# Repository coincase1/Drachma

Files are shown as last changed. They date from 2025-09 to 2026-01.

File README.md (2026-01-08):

30% Left-Handed Hall Effect Keypad

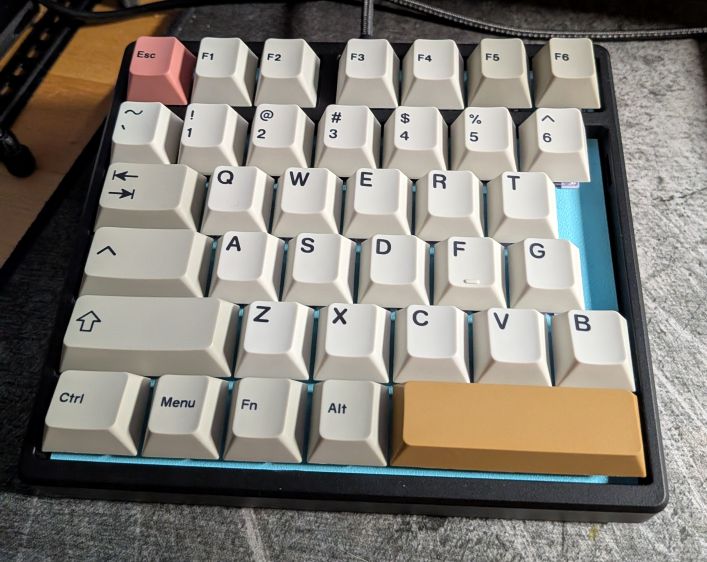
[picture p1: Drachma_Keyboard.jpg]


Based on / Inspired by [Peppapigh's HE60](https://github.com/peppapighs/HE60).

This keyboard is a PCB swap of the [Kisnt 34 Key Numpad](https://www.amazon.com/gp/product/B0C1H8V52D?smid=A1QSA46GV4FLI2&psc=1). With modifications to the top of the case using a hobby saw, this PCB fits inside of that case. The Drachma PCB connects to the Kisnt USB daughterboard using the provided Flat Conductor Cable. It also features a connection for a Pico-EZmate connector featured on Unified Daughterboards.

For anyone looking at this design at a later date, please be mindful of the Analog-to-Digital pins on the STM32F446 microcontroller. These can be verified on Sheets 46-56 of the STM32F446T MC Manual.

For HE switches, my recommendation are either OH49E-S or SS39ET from Honeywell. The OH49E-S are clones of these switches and these are featured in a number of big box HE board builds.

All Kicad and Firmware represents the latest (V3) Drachma build.

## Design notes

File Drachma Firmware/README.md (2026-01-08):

# Drachma

Drachma is a 37 key left-handed "30%" Hall-effect keyboard. The firmware here is for HMK.

- **Keyboard Maintainer**: [coincase]
- **Hardware Support**: [peppapighs/HE60](https://github.com/peppapighs/HE60)
- **Bootloader**: Factory STM32 DFU bootloader. Enter the bootloader through the following methods:
  - Hold **BOOT** button while plugging in the keyboard.
  - Press the `SP_BOOT` binding.
  - Use the web configurator.

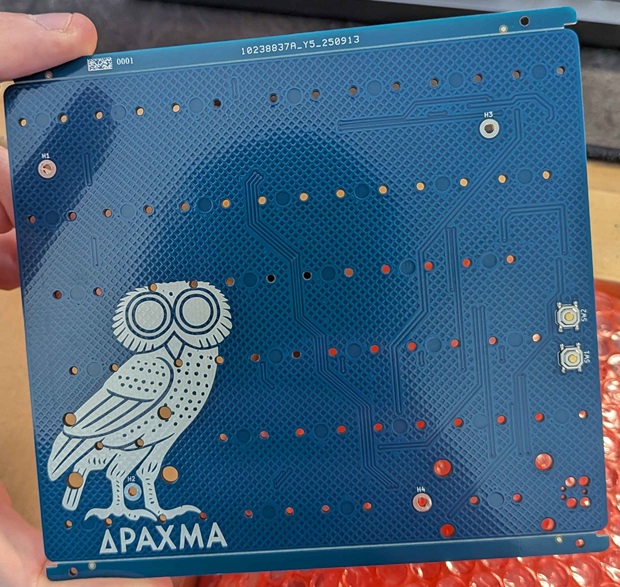
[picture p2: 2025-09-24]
Drachma V1_Front.jpg

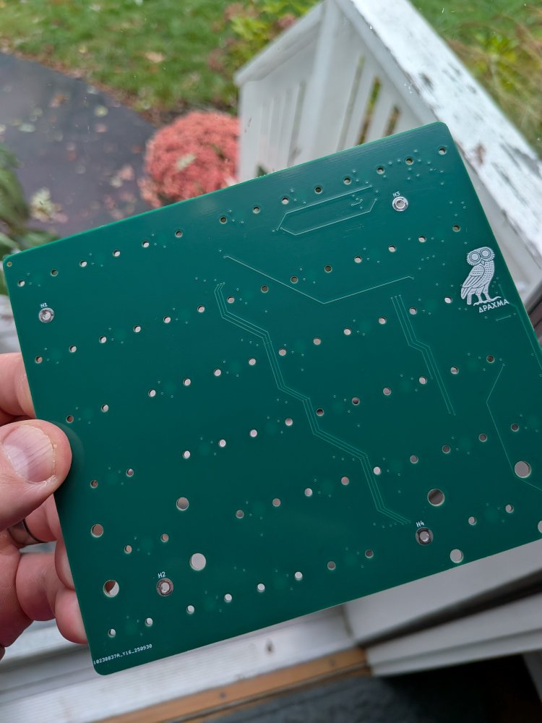
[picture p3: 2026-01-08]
Drachma V2_Front.jpg

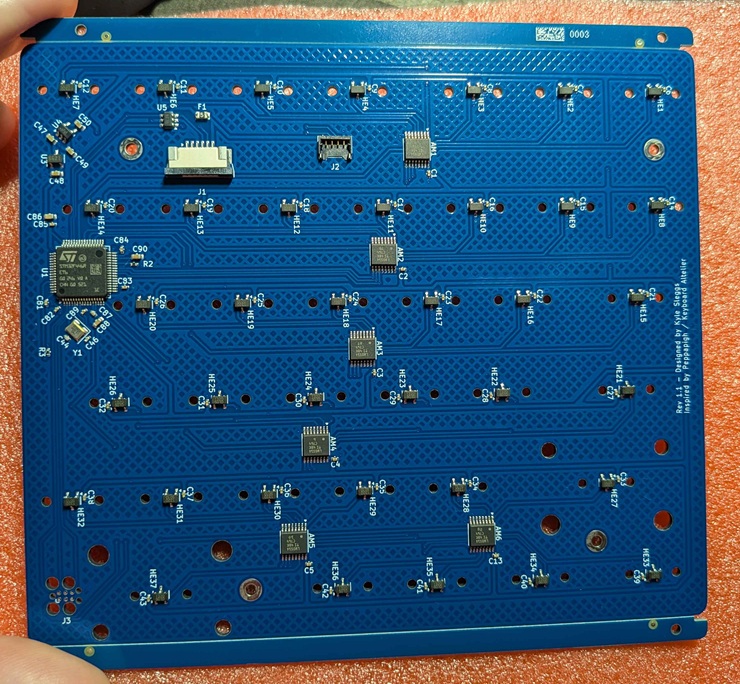
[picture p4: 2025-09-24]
Drachma V1_Back.jpg

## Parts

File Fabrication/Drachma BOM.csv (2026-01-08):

Comment | Designator | Value | Footprint | JLCPCB Part #
Analog Multiplexer | AM1 | SN74LV4051A | TSSOP-16_4.4x5mm_P0.65mm | C7793
Analog Multiplexer | AM2 | SN74LV4051A | TSSOP-16_4.4x5mm_P0.65mm | C7793
Analog Multiplexer | AM3 | SN74LV4051A | TSSOP-16_4.4x5mm_P0.65mm | C7793
Analog Multiplexer | AM4 | SN74LV4051A | TSSOP-16_4.4x5mm_P0.65mm | C7793
Analog Multiplexer | AM5 | SN74LV4051A | TSSOP-16_4.4x5mm_P0.65mm | C7793
Analog Multiplexer | AM6 | SN74LV4051A | TSSOP-16_4.4x5mm_P0.65mm | C7793
100n | C1 | 100n | C_0402_1005Metric | C1525
100n | C2 | 100n | C_0402_1005Metric | C1525
100n | C3 | 100n | C_0402_1005Metric | C1525
100n | C4 | 100n | C_0402_1005Metric | C1525
100n | C5 | 100n | C_0402_1005Metric | C1525
100n | C6 | 100n | C_0402_1005Metric | C1525
100n | C7 | 100n | C_0402_1005Metric | C1525
100n | C8 | 100n | C_0402_1005Metric | C1525
100n | C9 | 100n | C_0402_1005Metric | C1525
100n | C10 | 100n | C_0402_1005Metric | C1525
100n | C11 | 100n | C_0402_1005Metric | C1525
100n | C12 | 100n | C_0402_1005Metric | C1525
100n | C13 | 100n | C_0402_1005Metric | C1525
100n | C14 | 100n | C_0402_1005Metric | C1525
100n | C15 | 100n | C_0402_1005Metric | C1525
100n | C16 | 100n | C_0402_1005Metric | C1525
100n | C17 | 100n | C_0402_1005Metric | C1525
100n | C18 | 100n | C_0402_1005Metric | C1525
100n | C19 | 100n | C_0402_1005Metric | C1525
100n | C20 | 100n | C_0402_1005Metric | C1525
100n | C21 | 100n | C_0402_1005Metric | C1525
100n | C22 | 100n | C_0402_1005Metric | C1525
100n | C23 | 100n | C_0402_1005Metric | C1525
100n | C24 | 100n | C_0402_1005Metric | C1525
100n | C25 | 100n | C_0402_1005Metric | C1525
100n | C26 | 100n | C_0402_1005Metric | C1525
100n | C27 | 100n | C_0402_1005Metric | C1525
100n | C28 | 100n | C_0402_1005Metric | C1525
100n | C29 | 100n | C_0402_1005Metric | C1525
100n | C30 | 100n | C_0402_1005Metric | C1525
100n | C31 | 100n | C_0402_1005Metric | C1525
100n | C32 | 100n | C_0402_1005Metric | C1525
100n | C33 | 100n | C_0402_1005Metric | C1525
100n | C34 | 100n | C_0402_1005Metric | C1525
100n | C35 | 100n | C_0402_1005Metric | C1525
100n | C36 | 100n | C_0402_1005Metric | C1525
100n | C37 | 100n | C_0402_1005Metric | C1525
100n | C38 | 100n | C_0402_1005Metric | C1525
100n | C39 | 100n | C_0402_1005Metric | C1525
100n | C40 | 100n | C_0402_1005Metric | C1525
100n | C41 | 100n | C_0402_1005Metric | C1525
100n | C42 | 100n | C_0402_1005Metric | C1525
100n | C43 | 100n | C_0402_1005Metric | C1525
10p | C44 | 10p | C_0402_1005Metric | C32949
10p | C46 | 10p | C_0402_1005Metric | C32949
1u | C47 | 1u | C_0603_1608Metric | C15849
1u | C48 | 1u | C_0603_1608Metric | C15849
2.2u | C49 | 2.2u | C_0603_1608Metric | C23630
2.2u | C50 | 2.2u | C_0603_1608Metric | C23630
100n | C81 | 100n | C_0402_1005Metric | C1525
100n | C82 | 100n | C_0402_1005Metric | C1525
100n | C83 | 100n | C_0402_1005Metric | C1525
100n | C84 | 100n | C_0402_1005Metric | C1525
100n | C85 | 100n | C_0402_1005Metric | C1525
10u | C86 | 10u | C_0603_1608Metric | C19702
100n | C87 | 100n | C_0402_1005Metric | C1525
1u | C88 | 1u | C_0603_1608Metric | C15849
100n | C89 | 100n | C_0402_1005Metric | C1525
4.7u | C90 | 4.7u | C_0603_1608Metric | C19666
Fuse | F1 | BSMD0805-050-24V | Fuse_0805_2012Metric | C910822
Hall Effect Sensor | HE1 | SS39ET | SOT-23 | C126669
Hall Effect Sensor | HE2 | SS39ET | SOT-23 | C126669
Hall Effect Sensor | HE3 | SS39ET | SOT-23 | C126669
Hall Effect Sensor | HE4 | SS39ET | SOT-23 | C126669
Hall Effect Sensor | HE5 | SS39ET | SOT-23 | C126669
Hall Effect Sensor | HE6 | SS39ET | SOT-23 | C126669
Hall Effect Sensor | HE7 | SS39ET | SOT-23 | C126669
Hall Effect Sensor | HE8 | SS39ET | SOT-23 | C126669
Hall Effect Sensor | HE9 | SS39ET | SOT-23 | C126669
Hall Effect Sensor | HE10 | SS39ET | SOT-23 | C126669
Hall Effect Sensor | HE11 | SS39ET | SOT-23 | C126669
Hall Effect Sensor | HE12 | SS39ET | SOT-23 | C126669
Hall Effect Sensor | HE13 | SS39ET | SOT-23 | C126669
Hall Effect Sensor | HE14 | SS39ET | SOT-23 | C126669
Hall Effect Sensor | HE15 | SS39ET | SOT-23 | C126669
Hall Effect Sensor | HE16 | SS39ET | SOT-23 | C126669
Hall Effect Sensor | HE17 | SS39ET | SOT-23 | C126669
Hall Effect Sensor | HE18 | SS39ET | SOT-23 | C126669
Hall Effect Sensor | HE19 | SS39ET | SOT-23 | C126669
Hall Effect Sensor | HE20 | SS39ET | SOT-23 | C126669
Hall Effect Sensor | HE21 | SS39ET | SOT-23 | C126669
Hall Effect Sensor | HE22 | SS39ET | SOT-23 | C126669
Hall Effect Sensor | HE23 | SS39ET | SOT-23 | C126669
Hall Effect Sensor | HE24 | SS39ET | SOT-23 | C126669
Hall Effect Sensor | HE25 | SS39ET | SOT-23 | C126669
Hall Effect Sensor | HE26 | SS39ET | SOT-23 | C126669
Hall Effect Sensor | HE27 | SS39ET | SOT-23 | C126669
Hall Effect Sensor | HE28 | SS39ET | SOT-23 | C126669
Hall Effect Sensor | HE29 | SS39ET | SOT-23 | C126669
Hall Effect Sensor | HE30 | SS39ET | SOT-23 | C126669
Hall Effect Sensor | HE31 | SS39ET | SOT-23 | C126669
Hall Effect Sensor | HE32 | SS39ET | SOT-23 | C126669
Hall Effect Sensor | HE33 | SS39ET | SOT-23 | C126669
Hall Effect Sensor | HE34 | SS39ET | SOT-23 | C126669
Hall Effect Sensor | HE35 | SS39ET | SOT-23 | C126669
Hall Effect Sensor | HE36 | SS39ET | SOT-23 | C126669
Hall Effect Sensor | HE37 | SS39ET | SOT-23 | C126669
Conn_01x06 | J1 |  | JUSHUO_AFA07-S06FCA-00_1x6-1MP_P1.0mm_Horizontal | C262712
Conn_01x04 | J2 |  | Molex_Pico-EZmate_78171-0004_1x04-1MP_P1.20mm_Vertical | C588524
10k | R2 | 10k | R_0402_1005Metric | C25744
10k | R3 | 10k | R_0402_1005Metric | C25744
Switch | SW1 |  | SW_Push_1P1T_XKB_TS-1187A | C318884
Switch | SW2 |  | SW_Push_1P1T_XKB_TS-1187A | C318884
STM32F446RET6 | U1 |  | LQFP-64_10x10mm_P0.5mm | C69336
XC6206P332MR-G | U3 |  | SOT-23-3 | C5446
TLV75733PDBV | U4 |  | SOT-23-5 | C485517
USBLC6-2SC6 | U5 |  | SOT-23-6 | C7519
X322516MLB4SI | Y1 | Crystal_GND24 | Crystal_SMD_3225-4Pin_3.2x2.5mm | C13738

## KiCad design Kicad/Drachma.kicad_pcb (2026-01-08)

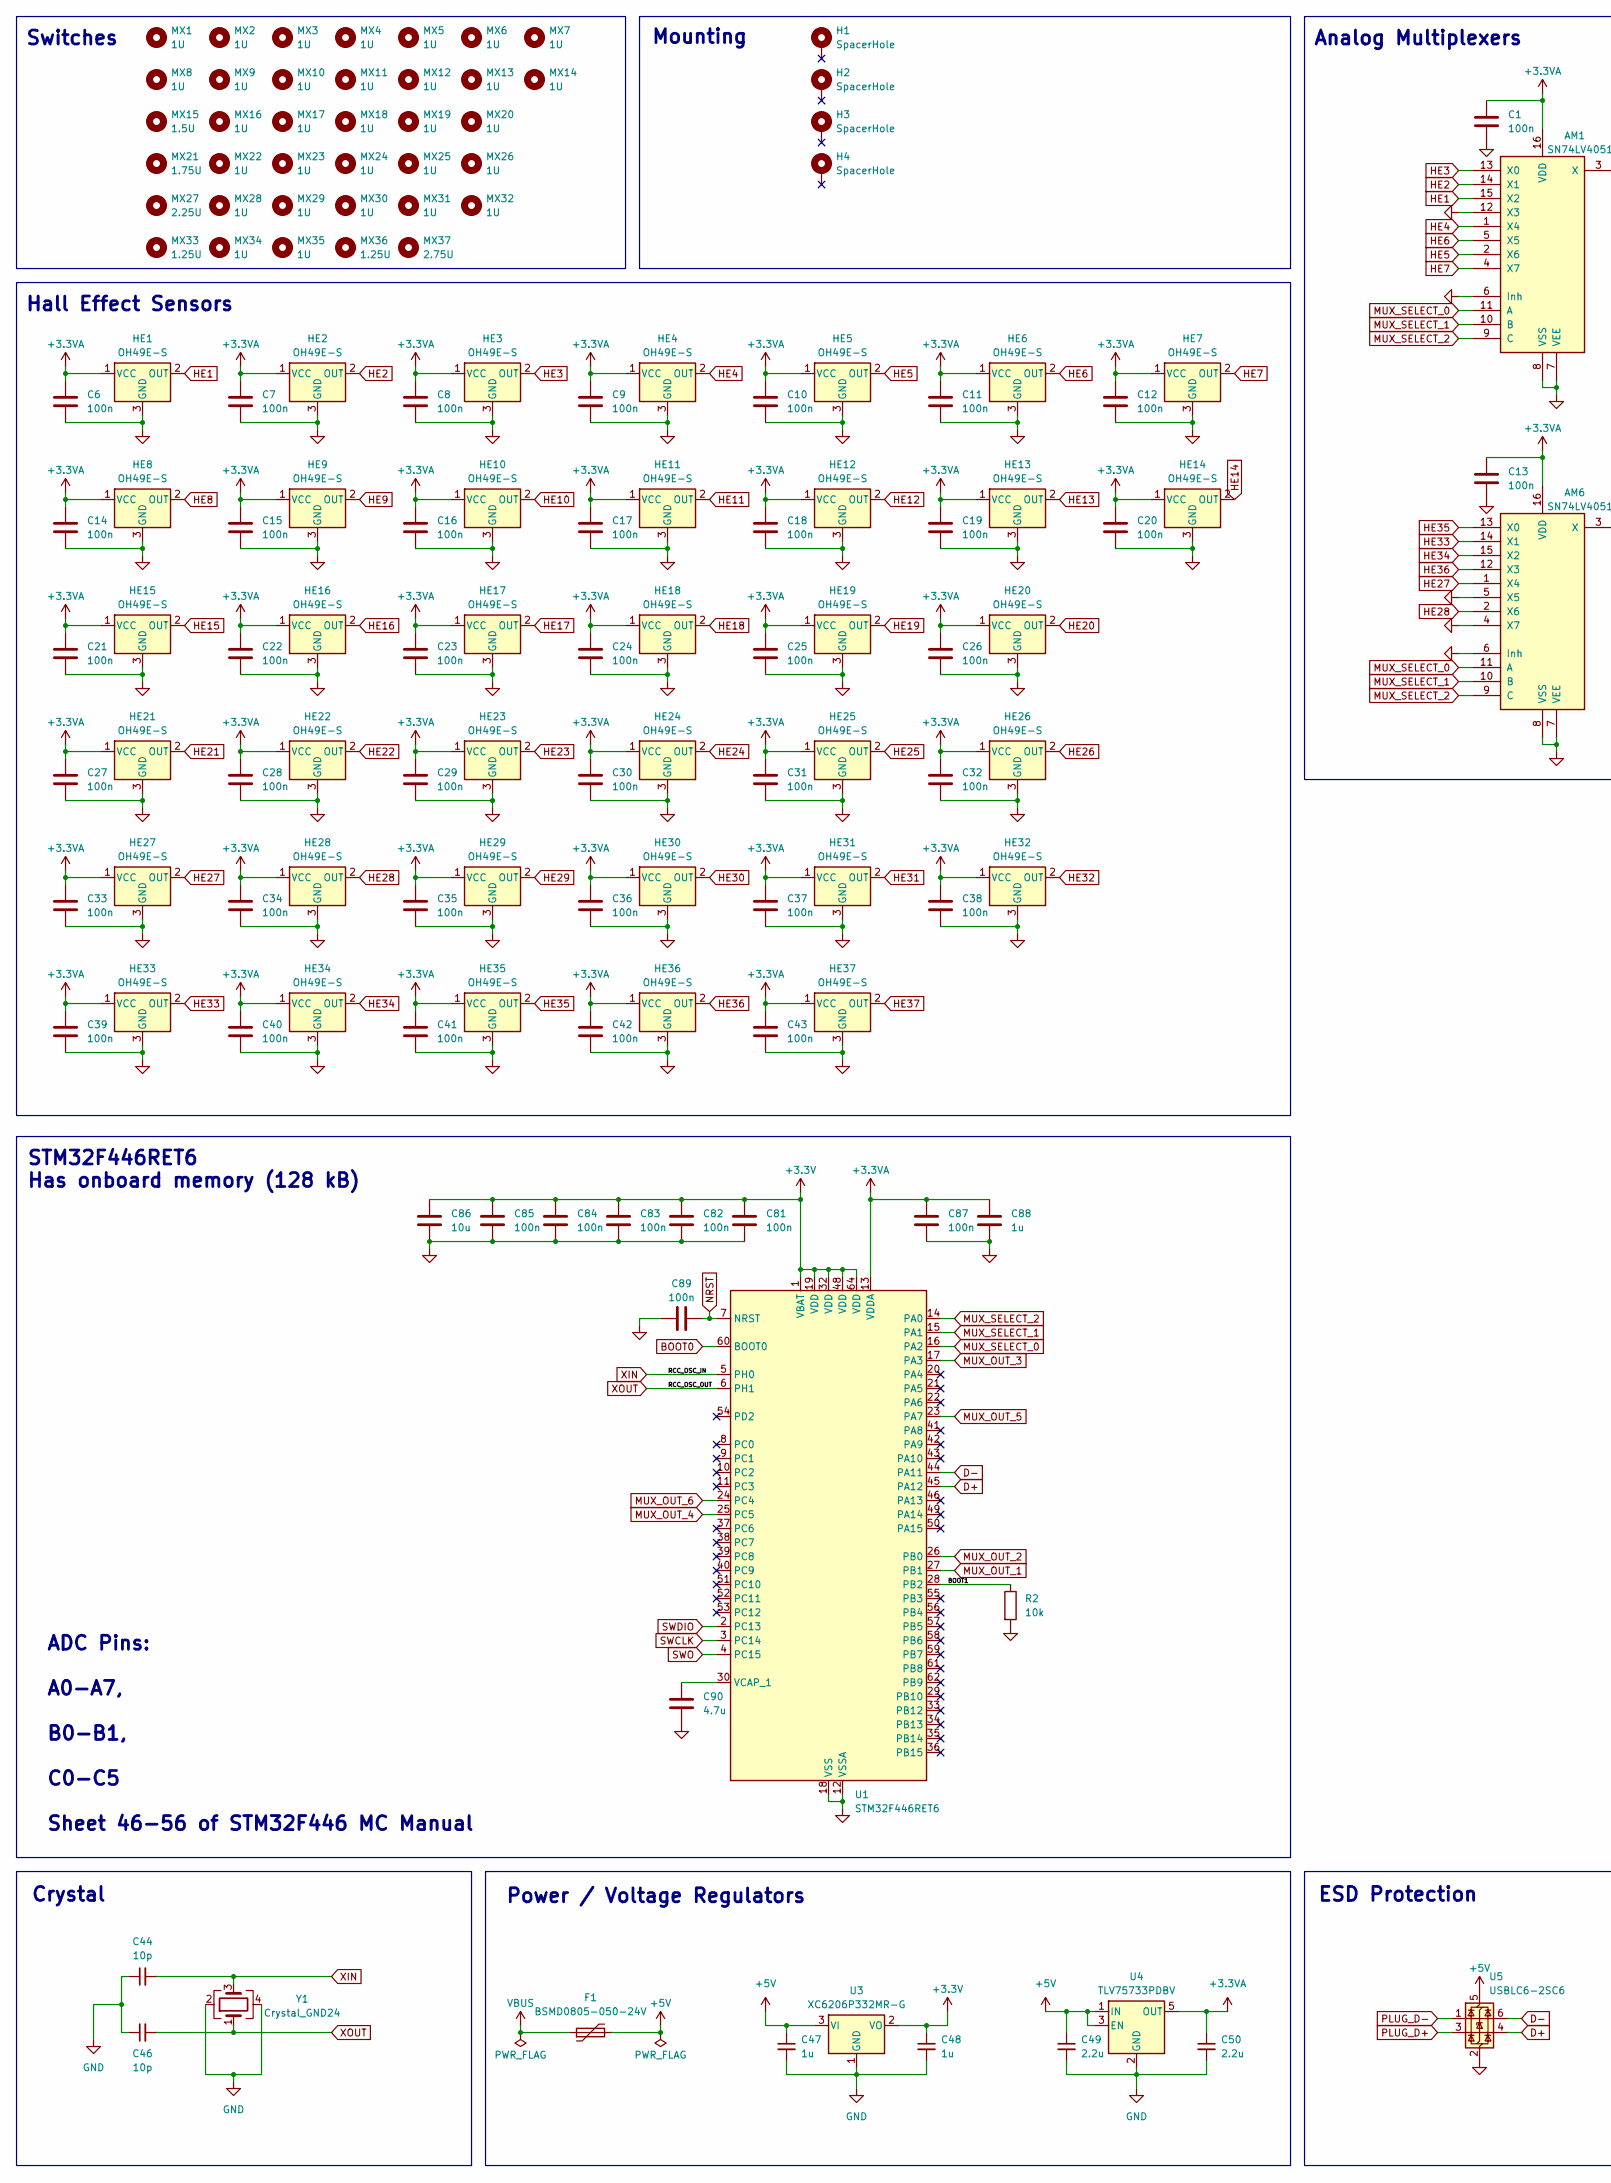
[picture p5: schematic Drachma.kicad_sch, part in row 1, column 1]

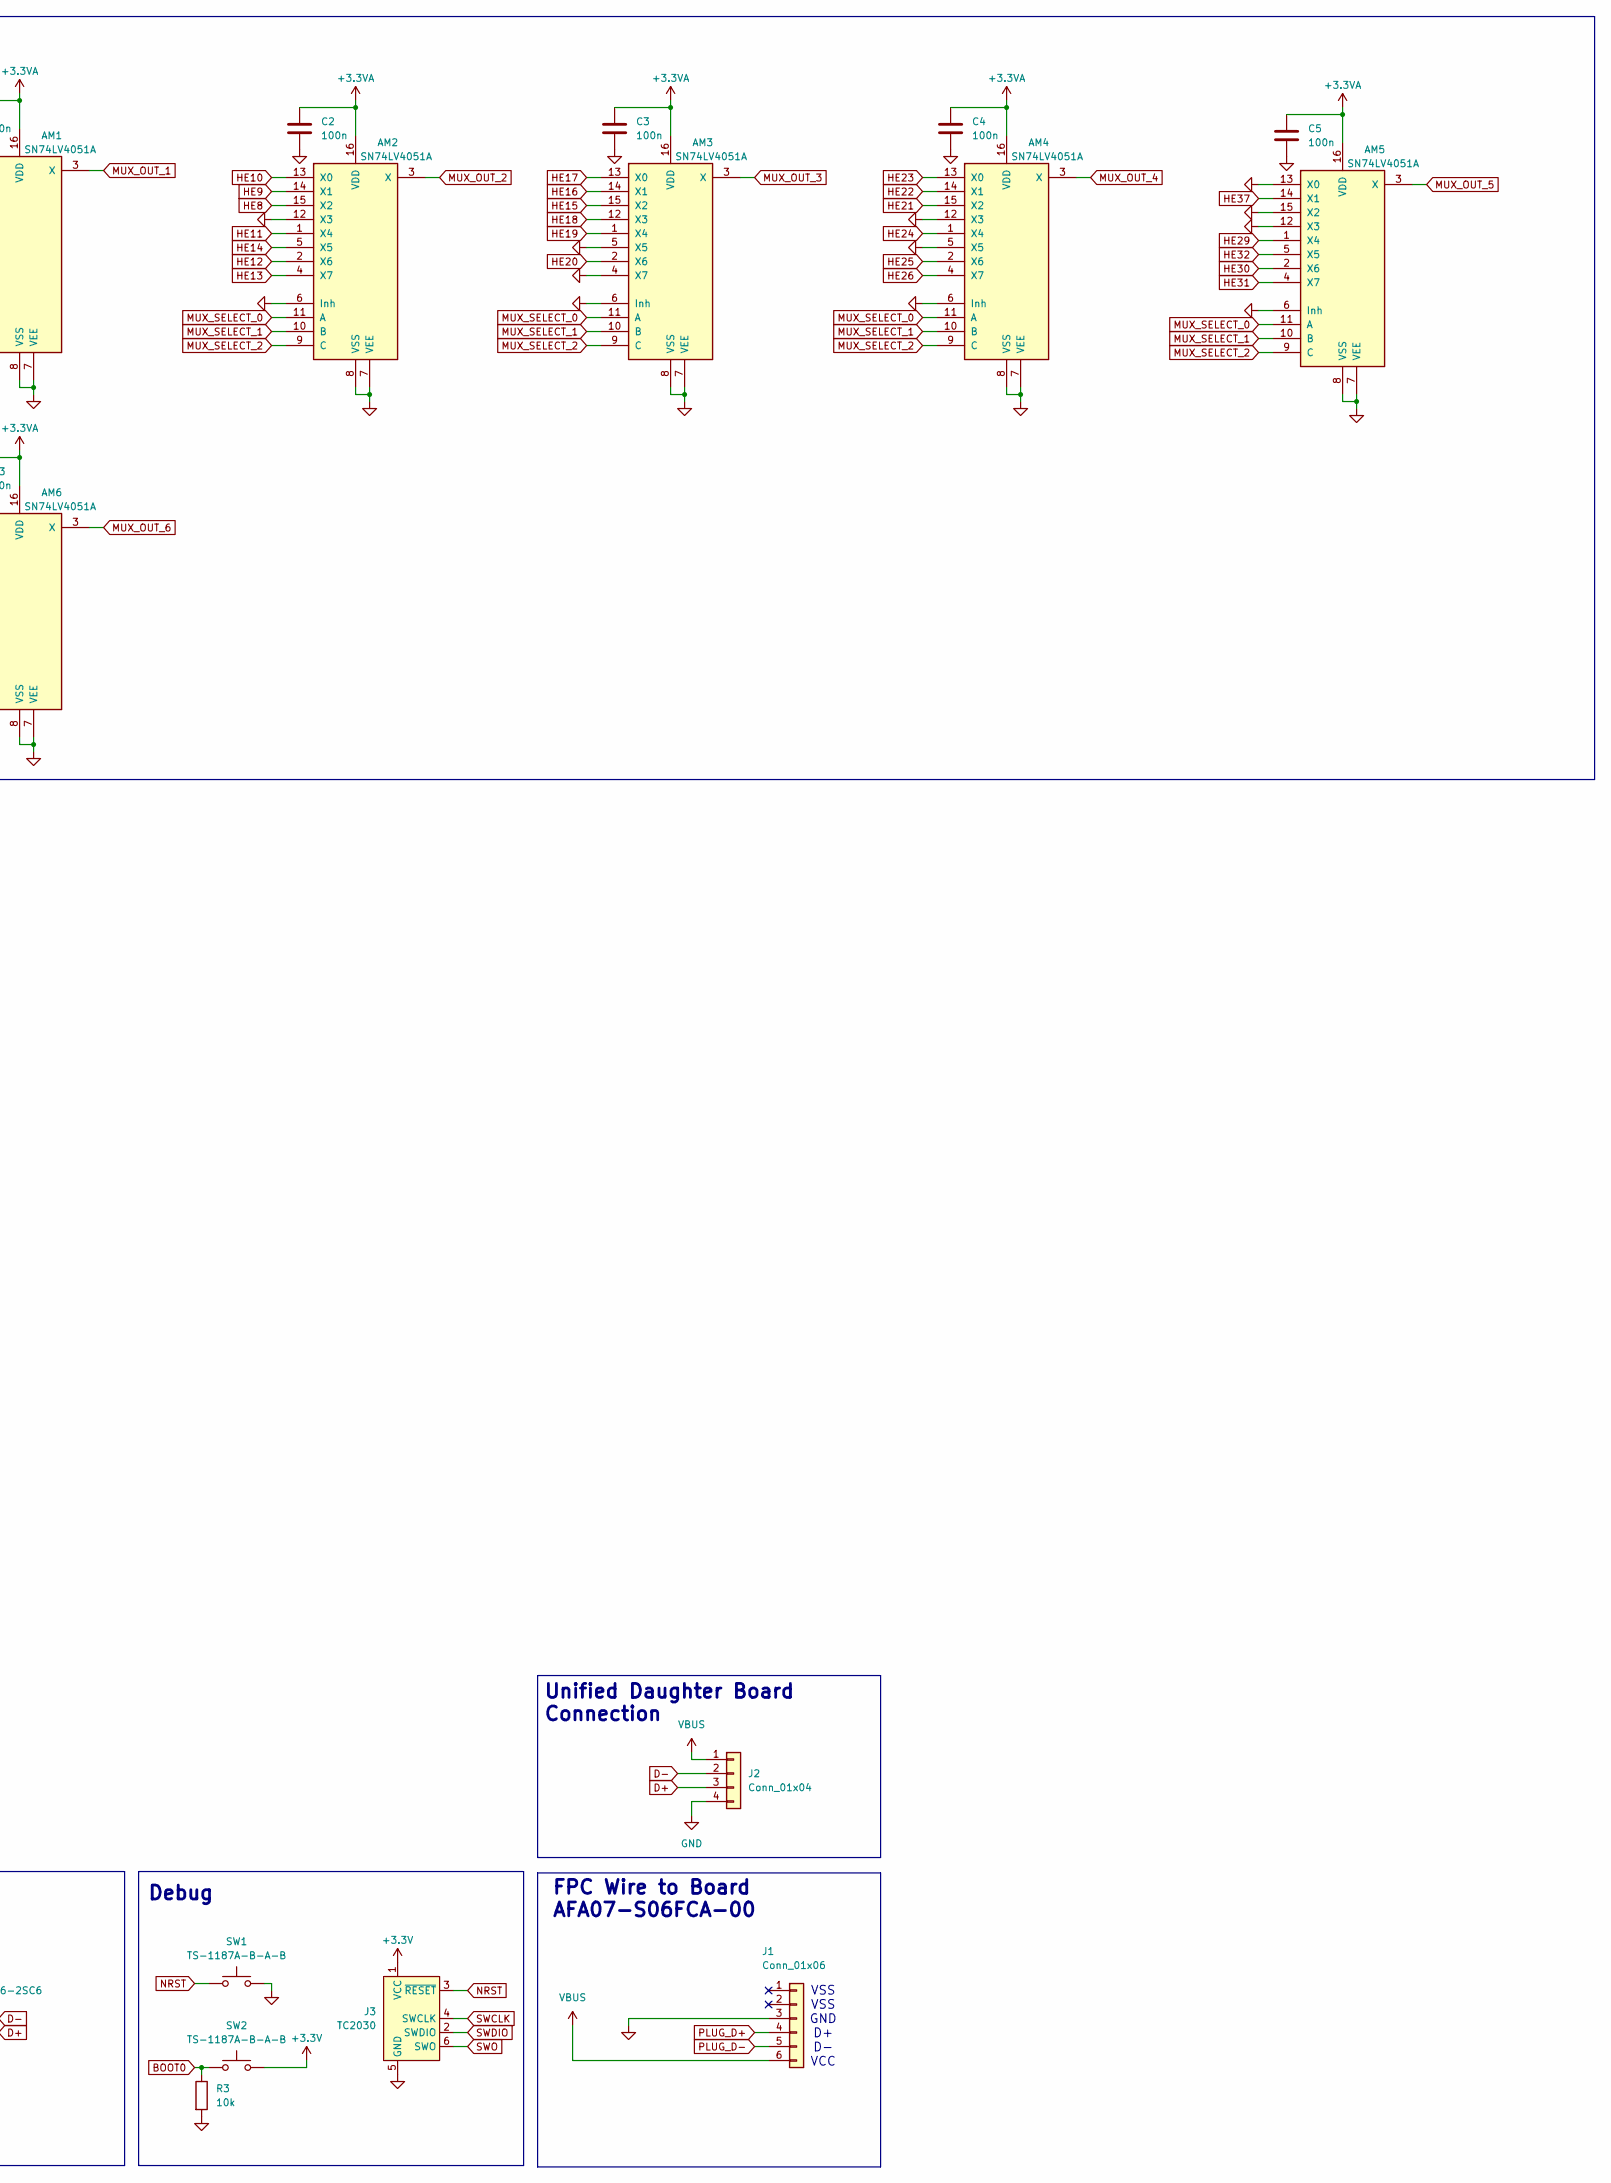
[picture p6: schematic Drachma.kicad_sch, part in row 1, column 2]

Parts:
AM1, AM2, AM3, AM4, AM5, AM6: SN74LV4051A; TSSOP-16_4.4x5mm_P0.65mm
C1, C2, C3, C4, C5, C6, C7, C8, C9, C10, C11, C12, C13, C14, C15, C16, C17, C18, C19, C20, C21, C22, C23, C24, C25, C26, C27, C28, C29, C30, C31, C32, C33, C34, C35, C36, C37, C38, C39, C40, C41, C42, C43, C81, C82, C83, C84, C85, C87, C89: 100n; C_0402_1005Metric
C44, C46: 10p; C_0402_1005Metric
C47, C48, C88: 1u; C_0603_1608Metric
C49, C50: 2.2u; C_0603_1608Metric
C86: 10u; C_0603_1608Metric
C90: 4.7u; C_0603_1608Metric
F1: BSMD0805-050-24V; Fuse_0805_2012Metric
H1, H2, H3, H4: SpacerHole; MountingHole_2.2mm_M2_Pad
HE1, HE2, HE3, HE4, HE5, HE6, HE7, HE8, HE9, HE10, HE11, HE12, HE13, HE14, HE15, HE16, HE17, HE18, HE19, HE20, HE21, HE22, HE23, HE24, HE25, HE26, HE27, HE28, HE29, HE30, HE31, HE32, HE33, HE34, HE35, HE36, HE37: OH49E-S; SOT-23-3
J1: Conn_01x06; JUSHUO_AFA07-S06FCA-00_1x6-1MP_P1.0mm_Horizontal
J2: Conn_01x04; Molex_Pico-EZmate_78171-0004_1x04-1MP_P1.20mm_Vertical
J3: TC2030; Tag-Connect_TC2030-IDC-FP_2x03_P1.27mm_Vertical
MX1, MX2, MX3, MX4, MX5, MX6, MX7, MX8, MX9, MX10, MX11, MX12, MX13, MX14, MX16, MX17, MX18, MX19, MX20, MX22, MX23, MX24, MX25, MX26, MX28, MX29, MX30, MX31, MX32, MX34, MX35: 1U; MX-1U
MX15: 1.5U; MX-1.5U
MX21: 1.75U; MX-1.75U
MX27: 2.25U; MX-2.25U
MX33, MX36: 1.25U; MX-1.25U
MX37: 2.75U; MX-2.75U-ReversedStabilizers
R2, R3: 10k; R_0402_1005Metric
SW1, SW2: TS-1187A-B-A-B; SW_Push_1P1T_XKB_TS-1187A
U1: STM32F446RET6; LQFP-64_10x10mm_P0.5mm
U3: XC6206P332MR-G; SOT-23-3
U4: TLV75733PDBV; SOT-23-5
U5: USBLC6-2SC6; SOT-23-6
Y1: Crystal_GND24; Crystal_SMD_3225-4Pin_3.2x2.5mm

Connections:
+3.3V: C48.1, C81.1, C82.1, C83.1, C84.1, C85.1, C86.1, J3.1 (VCC), SW2.2, U1.1 (VBAT), U1.19 (VDD), U1.32 (VDD), U1.48 (VDD), U1.64 (VDD), U3.2 (VO)
+3.3VA: AM1.16 (VDD), AM2.16 (VDD), AM3.16 (VDD), AM4.16 (VDD), AM5.16 (VDD), AM6.16 (VDD), C1.1, C2.1, C3.1, C4.1, C5.1, C6.1, C7.1, C8.1, C9.1, C10.1, C11.1, C12.1, C13.1, C14.1, C15.1, C16.1, C17.1, C18.1, C19.1, C20.1, C21.1, C22.1, C23.1, C24.1, C25.1, C26.1, C27.1, C28.1, C29.1, C30.1, C31.1, C32.1, C33.1, C34.1, C35.1, C36.1, C37.1, C38.1, C39.1, C40.1, C41.1, C42.1, C43.1, C50.1, C87.1, C88.1, HE1.1 (VCC), HE2.1 (VCC), HE3.1 (VCC), HE4.1 (VCC), HE5.1 (VCC), HE6.1 (VCC), HE7.1 (VCC), HE8.1 (VCC), HE9.1 (VCC), HE10.1 (VCC), HE11.1 (VCC), HE12.1 (VCC), HE13.1 (VCC), HE14.1 (VCC), HE15.1 (VCC), HE16.1 (VCC), HE17.1 (VCC), HE18.1 (VCC), HE19.1 (VCC), HE20.1 (VCC), HE21.1 (VCC), HE22.1 (VCC), HE23.1 (VCC), HE24.1 (VCC), HE25.1 (VCC), HE26.1 (VCC), HE27.1 (VCC), HE28.1 (VCC), HE29.1 (VCC), HE30.1 (VCC), HE31.1 (VCC), HE32.1 (VCC), HE33.1 (VCC), HE34.1 (VCC), HE35.1 (VCC), HE36.1 (VCC), HE37.1 (VCC), U1.13 (VDDA), U4.5 (OUT)
+5V: C47.1, C49.1, F1.2, U3.3 (VI), U4.1 (IN), U4.3 (EN), U5.5 (VBUS)
/BOOT1: R2.1, U1.28 (PB2)
BOOT0: R3.1, SW2.1, U1.60 (BOOT0)
D+: J2.3, U1.45 (PA12), U5.4 (I/O2)
D-: J2.2, U1.44 (PA11), U5.6 (I/O1)
GND: AM1.6 (Inh), AM1.7 (VEE), AM1.8 (VSS), AM1.12 (X3), AM2.6 (Inh), AM2.7 (VEE), AM2.8 (VSS), AM2.12 (X3), AM3.4 (X7), AM3.5 (X5), AM3.6 (Inh), AM3.7 (VEE), AM3.8 (VSS), AM4.5 (X5), AM4.6 (Inh), AM4.7 (VEE), AM4.8 (VSS), AM4.12 (X3), AM5.6 (Inh), AM5.7 (VEE), AM5.8 (VSS), AM5.12 (X3), AM5.13 (X0), AM5.15 (X2), AM6.4 (X7), AM6.5 (X5), AM6.6 (Inh), AM6.7 (VEE), AM6.8 (VSS), C1.2, C2.2, C3.2, C4.2, C5.2, C6.2, C7.2, C8.2, C9.2, C10.2, C11.2, C12.2, C13.2, C14.2, C15.2, C16.2, C17.2, C18.2, C19.2, C20.2, C21.2, C22.2, C23.2, C24.2, C25.2, C26.2, C27.2, C28.2, C29.2, C30.2, C31.2, C32.2, C33.2, C34.2, C35.2, C36.2, C37.2, C38.2, C39.2, C40.2, C41.2, C42.2, C43.2, C44.1, C46.1, C47.2, C48.2, C49.2, C50.2, C81.2, C82.2, C83.2, C84.2, C85.2, C86.2, C87.2, C88.2, C89.1, C90.2, HE1.3 (GND), HE2.3 (GND), HE3.3 (GND), HE4.3 (GND), HE5.3 (GND), HE6.3 (GND), HE7.3 (GND), HE8.3 (GND), HE9.3 (GND), HE10.3 (GND), HE11.3 (GND), HE12.3 (GND), HE13.3 (GND), HE14.3 (GND), HE15.3 (GND), HE16.3 (GND), HE17.3 (GND), HE18.3 (GND), HE19.3 (GND), HE20.3 (GND), HE21.3 (GND), HE22.3 (GND), HE23.3 (GND), HE24.3 (GND), HE25.3 (GND), HE26.3 (GND), HE27.3 (GND), HE28.3 (GND), HE29.3 (GND), HE30.3 (GND), HE31.3 (GND), HE32.3 (GND), HE33.3 (GND), HE34.3 (GND), HE35.3 (GND), HE36.3 (GND), HE37.3 (GND), J1.3, J2.4, J3.5 (GND), R2.2, R3.2, SW1.2, U1.12 (VSSA), U1.18 (VSS), U1.31 (VSS), U1.47 (VSS), U1.63 (VSS), U3.1 (GND), U4.2 (GND), U5.2 (GND), Y1.2, Y1.4
HE1: AM1.15 (X2), HE1.2 (OUT)
HE2: AM1.14 (X1), HE2.2 (OUT)
HE3: AM1.13 (X0), HE3.2 (OUT)
HE4: AM1.1 (X4), HE4.2 (OUT)
HE5: AM1.2 (X6), HE5.2 (OUT)
HE6: AM1.5 (X5), HE6.2 (OUT)
HE7: AM1.4 (X7), HE7.2 (OUT)
HE8: AM2.15 (X2), HE8.2 (OUT)
HE9: AM2.14 (X1), HE9.2 (OUT)
HE10: AM2.13 (X0), HE10.2 (OUT)
HE11: AM2.1 (X4), HE11.2 (OUT)
HE12: AM2.2 (X6), HE12.2 (OUT)
HE13: AM2.4 (X7), HE13.2 (OUT)
HE14: AM2.5 (X5), HE14.2 (OUT)
HE15: AM3.15 (X2), HE15.2 (OUT)
HE16: AM3.14 (X1), HE16.2 (OUT)
HE17: AM3.13 (X0), HE17.2 (OUT)
HE18: AM3.12 (X3), HE18.2 (OUT)
HE19: AM3.1 (X4), HE19.2 (OUT)
HE20: AM3.2 (X6), HE20.2 (OUT)
HE21: AM4.15 (X2), HE21.2 (OUT)
HE22: AM4.14 (X1), HE22.2 (OUT)
HE23: AM4.13 (X0), HE23.2 (OUT)
HE24: AM4.1 (X4), HE24.2 (OUT)
HE25: AM4.2 (X6), HE25.2 (OUT)
HE26: AM4.4 (X7), HE26.2 (OUT)
HE27: AM6.1 (X4), HE27.2 (OUT)
HE28: AM6.2 (X6), HE28.2 (OUT)
HE29: AM5.1 (X4), HE29.2 (OUT)
HE30: AM5.2 (X6), HE30.2 (OUT)
HE31: AM5.4 (X7), HE31.2 (OUT)
HE32: AM5.5 (X5), HE32.2 (OUT)
HE33: AM6.14 (X1), HE33.2 (OUT)
HE34: AM6.15 (X2), HE34.2 (OUT)
HE35: AM6.13 (X0), HE35.2 (OUT)
HE36: AM6.12 (X3), HE36.2 (OUT)
HE37: AM5.14 (X1), HE37.2 (OUT)
MUX_OUT_1: AM1.3 (X), U1.27 (PB1)
MUX_OUT_2: AM2.3 (X), U1.26 (PB0)
MUX_OUT_3: AM3.3 (X), U1.17 (PA3)
MUX_OUT_4: AM4.3 (X), U1.25 (PC5)
MUX_OUT_5: AM5.3 (X), U1.23 (PA7)
MUX_OUT_6: AM6.3 (X), U1.24 (PC4)
MUX_SELECT_0: AM1.11 (A), AM2.11 (A), AM3.11 (A), AM4.11 (A), AM5.11 (A), AM6.11 (A), U1.16 (PA2)
MUX_SELECT_1: AM1.10 (B), AM2.10 (B), AM3.10 (B), AM4.10 (B), AM5.10 (B), AM6.10 (B), U1.15 (PA1)
MUX_SELECT_2: AM1.9 (C), AM2.9 (C), AM3.9 (C), AM4.9 (C), AM5.9 (C), AM6.9 (C), U1.14 (PA0)
NRST: C89.2, J3.3 (~RESET), SW1.1, U1.7 (NRST)
unnamed: C90.1, U1.30 (VCAP_1)
PLUG_D+: J1.4, U5.3 (I/O2)
PLUG_D-: J1.5, U5.1 (I/O1)
SWCLK: J3.4 (SWCLK), U1.3 (PC14)
SWDIO: J3.2 (SWDIO), U1.2 (PC13)
SWO: J3.6 (SWO), U1.4 (PC15)
VBUS: F1.1, J1.6, J2.1
XIN: C44.2, U1.5 (PH0), Y1.3
XOUT: C46.2, U1.6 (PH1), Y1.1

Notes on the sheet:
VSS VSS GND D+ D- VCC
STM32F446RET6 Has onboard memory (128 kB)
Mounting
ESD Protection
Switches
FPC Wire to Board AFA07-S06FCA-00
ADC Pins: A0-A7, B0-B1, C0-C5 Sheet 46-56 of STM32F446 MC Manual
Analog Multiplexers
Hall Effect Sensors
Unified Daughter Board Connection
Power / Voltage Regulators
Crystal
Debug

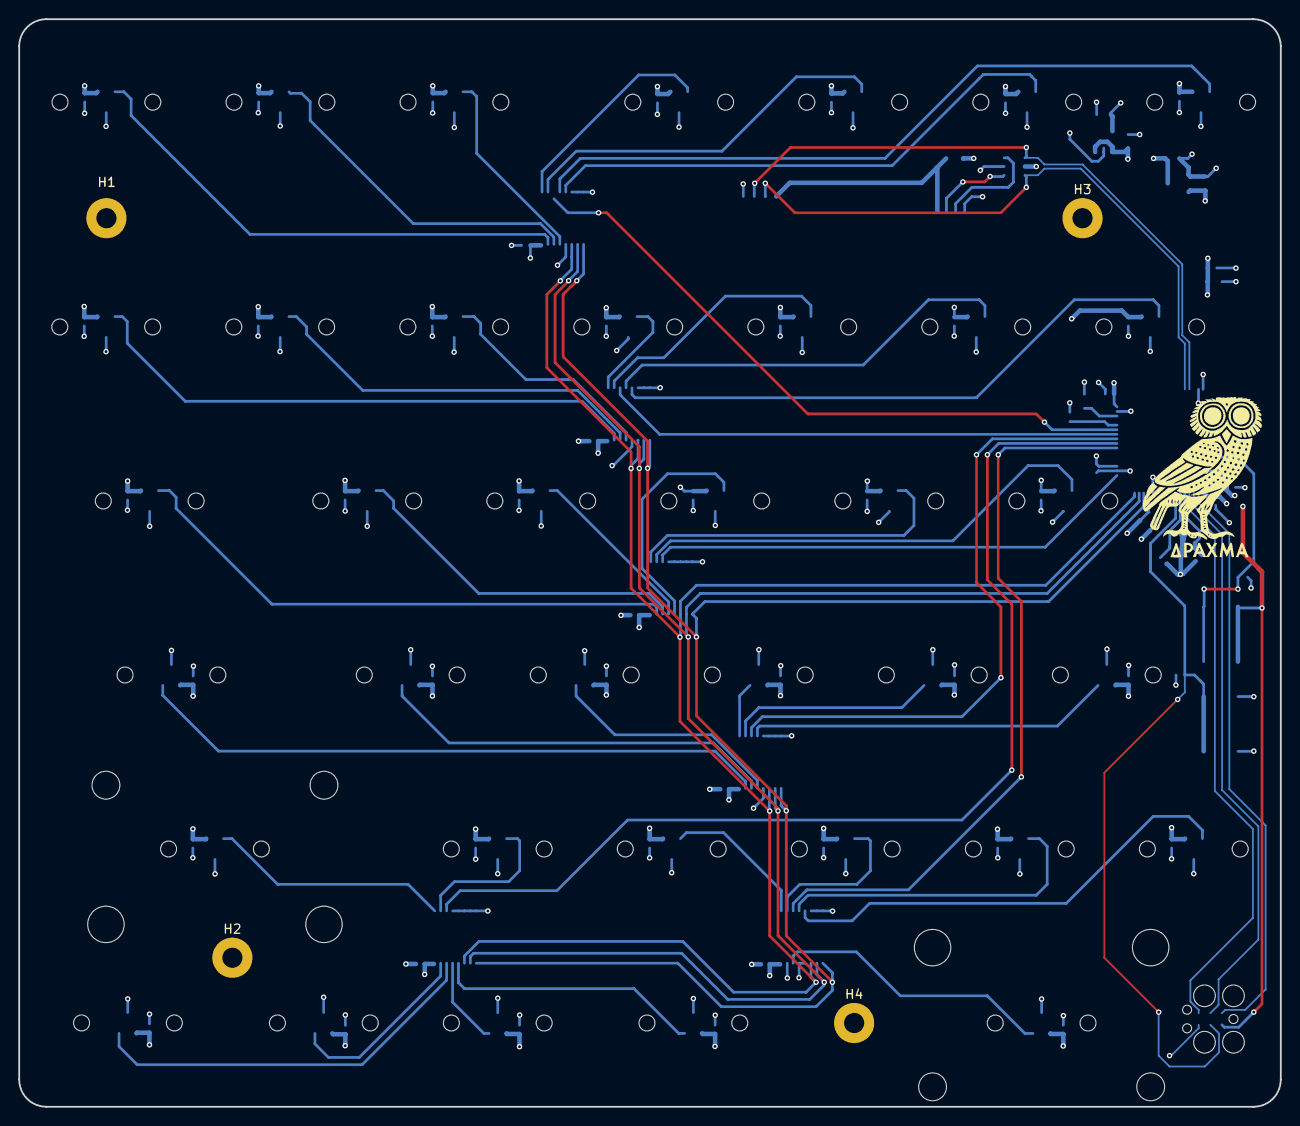
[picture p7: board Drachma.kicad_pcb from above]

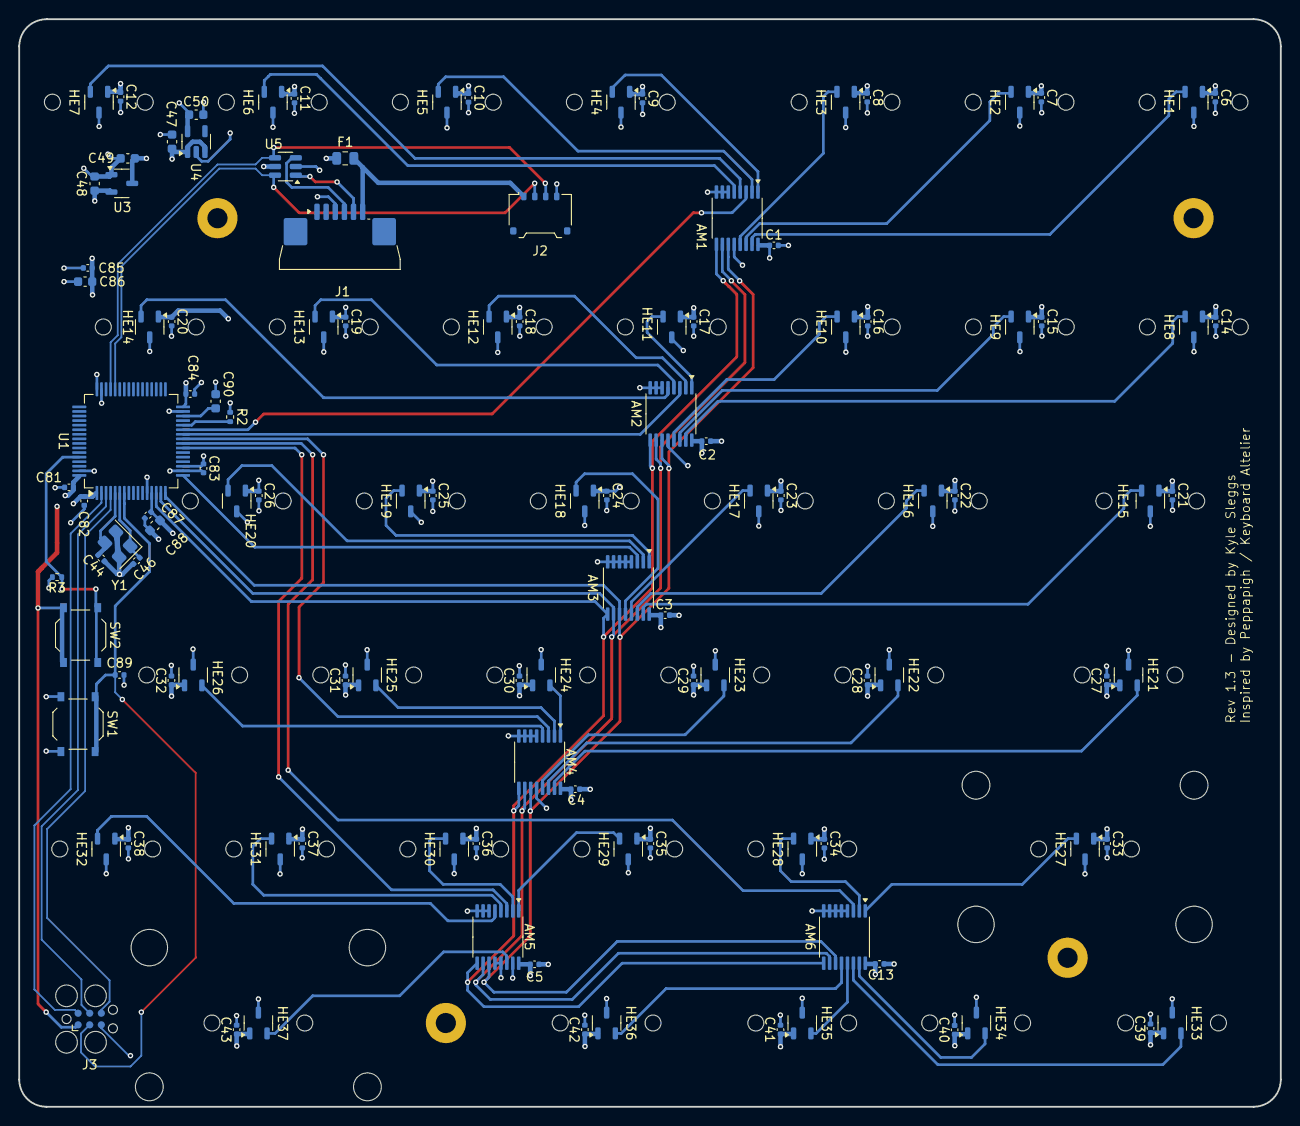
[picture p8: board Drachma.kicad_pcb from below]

Board: 4 copper layers, 138.1 x 119.1 mm, 156 parts (115 on the bottom side), 64 nets.

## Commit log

2026-01-08 Modify hardware settings and calibration values
    Updated hardware configuration and calibration values in keyboard.json.
2026-01-08 Create Kicad
2026-01-08 Update README with Kicad and Firmware version info
    Added a note about Kicad and Firmware version.
